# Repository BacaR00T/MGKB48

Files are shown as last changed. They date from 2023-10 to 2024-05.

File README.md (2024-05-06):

# MGKB48
Left and right part connects to the main powerboard with nice!nano (or any another pro micro pinout MCU). 

mgkb48_fin

# MCU file configuration
To be able to use the nice!nano (or any other MCU with nRF52840) and KMK, it's needed to flash the MCU with [CircuitPython](https://learn.adafruit.com/welcome-to-circuitpython/installing-circuitpython) and then compile the [kmk library](https://kmkfw.io/docs/Getting_Started)

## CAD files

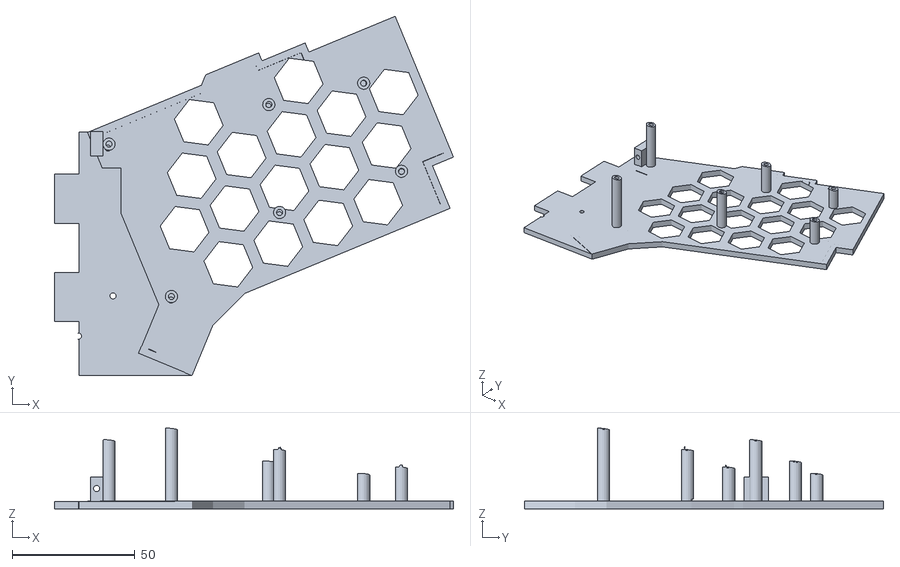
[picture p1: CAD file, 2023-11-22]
STL/MGKB48_RIGHT.stl
162.4 x 146.2 x 32.8

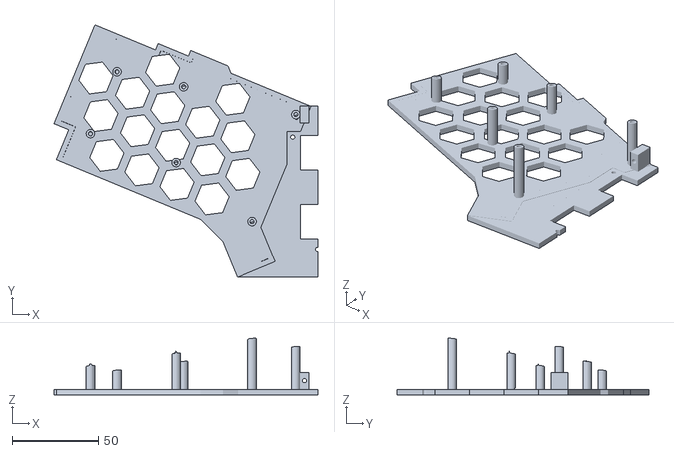
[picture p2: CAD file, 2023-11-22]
STL/MGKB48_LEFT.stl
153.0 x 146.3 x 32.8

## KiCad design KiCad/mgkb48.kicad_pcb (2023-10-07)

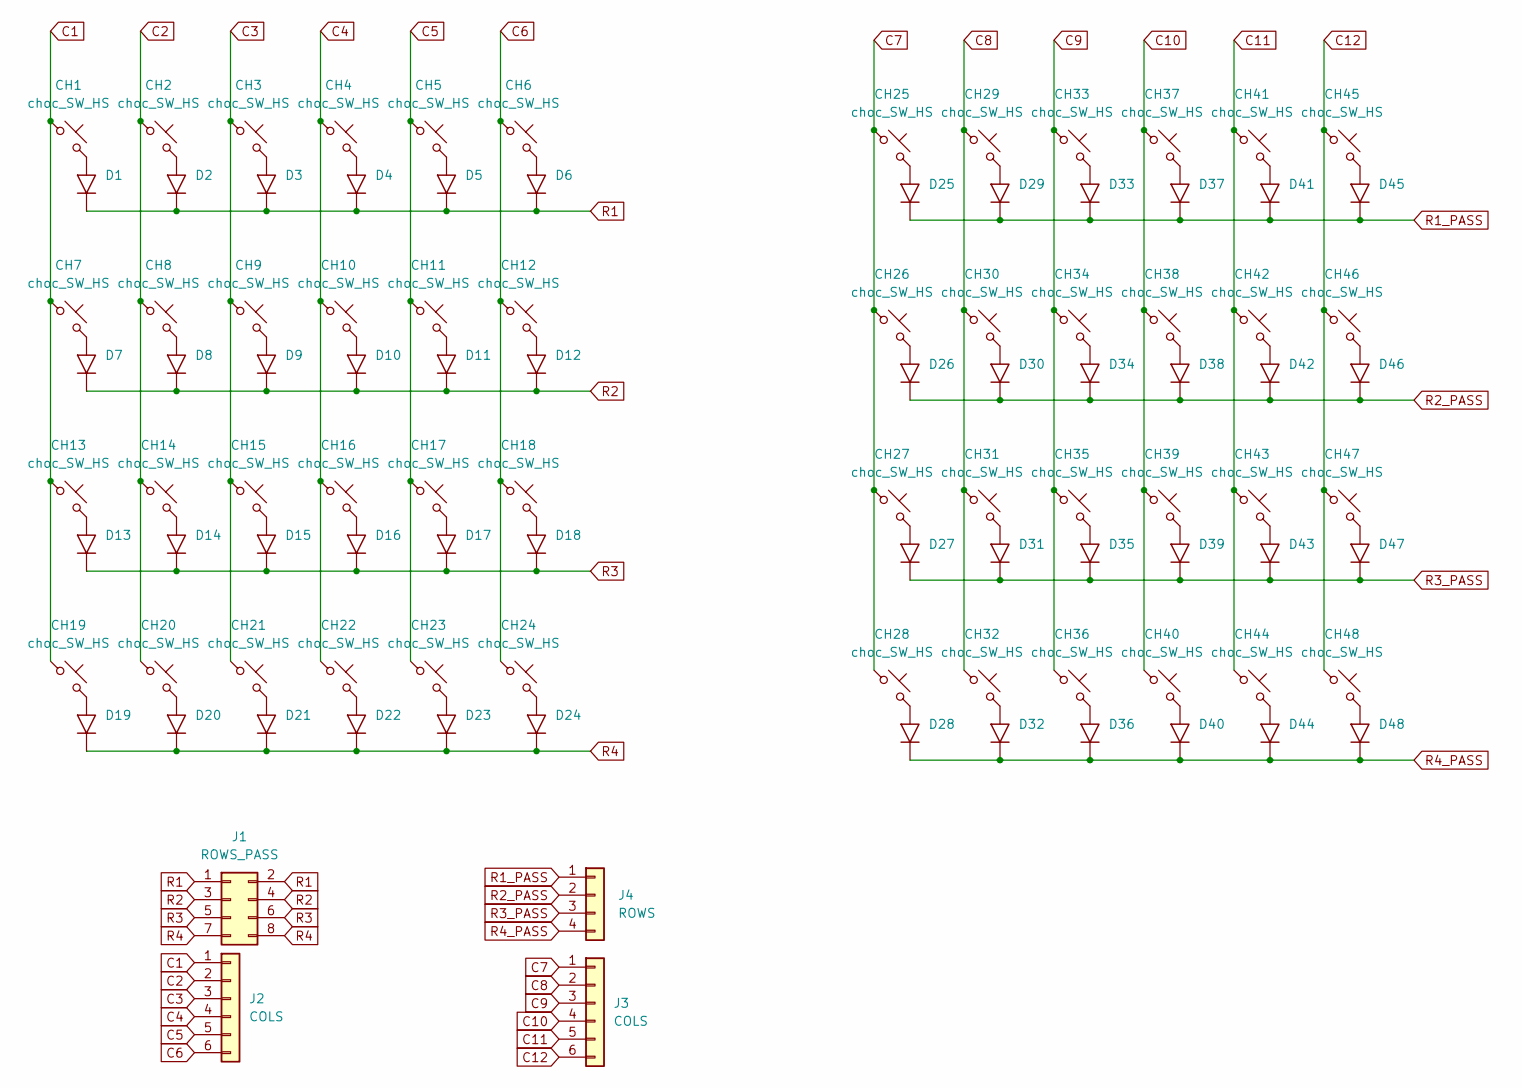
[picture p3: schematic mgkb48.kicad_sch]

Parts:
CH1, CH2, CH3, CH4, CH5, CH6, CH7, CH8, CH9, CH10, CH11, CH12, CH13, CH14, CH15, CH16, CH17, CH18, CH19, CH20, CH21, CH22, CH23, CH24, CH25, CH26, CH27, CH28, CH29, CH30, CH31, CH32, CH33, CH34, CH35, CH36, CH37, CH38, CH39, CH40, CH41, CH42, CH43, CH44, CH45, CH46, CH47, CH48: choc_SW_HS; SW_choc_v1_HS_1u
D1, D2, D3, D4, D5, D6, D7, D8, D9, D10, D11, D12, D13, D14, D15, D16, D17, D18, D19, D20, D21, D22, D23, D24, D25, D26, D27, D28, D29, D30, D31, D32, D33, D34, D35, D36, D37, D38, D39, D40, D41, D42, D43, D44, D45, D46, D47, D48: D_Generic; D_DO-35_P7.62mm_Horizontal
J1: ROWS_PASS; Pins_2x04_2.54mm_TH; Part Number 1-0802FBV0T
J2, J3: COLS; Pins_1x06_2.54mm_TH_SWD; Part Number 1-0601FBV0T
J4: ROWS; Pins_1x04_2.54mm_TH; Part Number 1-0401FBV0T

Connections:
C1: CH1.1, CH7.1, CH13.1, CH19.1, J2.1
C2: CH2.1, CH8.1, CH14.1, CH20.1, J2.2
C3: CH3.1, CH9.1, CH15.1, CH21.1, J2.3
C4: CH4.1, CH10.1, CH16.1, CH22.1, J2.4
C5: CH5.1, CH11.1, CH17.1, CH23.1, J2.5
C6: CH6.1, CH12.1, CH18.1, CH24.1, J2.6
C7: CH25.1, CH26.1, CH27.1, CH28.1, J3.1
C8: CH29.1, CH30.1, CH31.1, CH32.1, J3.2
C9: CH33.1, CH34.1, CH35.1, CH36.1, J3.3
C10: CH37.1, CH38.1, CH39.1, CH40.1, J3.4
C11: CH41.1, CH42.1, CH43.1, CH44.1, J3.5
C12: CH45.1, CH46.1, CH47.1, CH48.1, J3.6
unnamed: CH1.2, D1.2 (A)
unnamed: CH2.2, D2.2 (A)
unnamed: CH3.2, D3.2 (A)
unnamed: CH4.2, D4.2 (A)
unnamed: CH5.2, D5.2 (A)
unnamed: CH6.2, D6.2 (A)
unnamed: CH7.2, D7.2 (A)
unnamed: CH8.2, D8.2 (A)
unnamed: CH9.2, D9.2 (A)
unnamed: CH10.2, D10.2 (A)
unnamed: CH11.2, D11.2 (A)
unnamed: CH12.2, D12.2 (A)
unnamed: CH13.2, D13.2 (A)
unnamed: CH14.2, D14.2 (A)
unnamed: CH15.2, D15.2 (A)
unnamed: CH16.2, D16.2 (A)
unnamed: CH17.2, D17.2 (A)
unnamed: CH18.2, D18.2 (A)
unnamed: CH19.2, D19.2 (A)
unnamed: CH20.2, D20.2 (A)
unnamed: CH21.2, D21.2 (A)
unnamed: CH22.2, D22.2 (A)
unnamed: CH23.2, D23.2 (A)
unnamed: CH24.2, D24.2 (A)
unnamed: CH25.2, D25.2 (A)
unnamed: CH26.2, D26.2 (A)
unnamed: CH27.2, D27.2 (A)
unnamed: CH28.2, D28.2 (A)
unnamed: CH29.2, D29.2 (A)
unnamed: CH30.2, D30.2 (A)
unnamed: CH31.2, D31.2 (A)
unnamed: CH32.2, D32.2 (A)
unnamed: CH33.2, D33.2 (A)
unnamed: CH34.2, D34.2 (A)
unnamed: CH35.2, D35.2 (A)
unnamed: CH36.2, D36.2 (A)
unnamed: CH37.2, D37.2 (A)
unnamed: CH38.2, D38.2 (A)
unnamed: CH39.2, D39.2 (A)
unnamed: CH40.2, D40.2 (A)
unnamed: CH41.2, D41.2 (A)
unnamed: CH42.2, D42.2 (A)
unnamed: CH43.2, D43.2 (A)
unnamed: CH44.2, D44.2 (A)
unnamed: CH45.2, D45.2 (A)
unnamed: CH46.2, D46.2 (A)
unnamed: CH47.2, D47.2 (A)
unnamed: CH48.2, D48.2 (A)
R1: D1.1 (K), D2.1 (K), D3.1 (K), D4.1 (K), D5.1 (K), D6.1 (K), J1.1, J1.2
R1_PASS: D25.1 (K), D29.1 (K), D33.1 (K), D37.1 (K), D41.1 (K), D45.1 (K), J4.1
R2: D7.1 (K), D8.1 (K), D9.1 (K), D10.1 (K), D11.1 (K), D12.1 (K), J1.3, J1.4
R2_PASS: D26.1 (K), D30.1 (K), D34.1 (K), D38.1 (K), D42.1 (K), D46.1 (K), J4.2
R3: D13.1 (K), D14.1 (K), D15.1 (K), D16.1 (K), D17.1 (K), D18.1 (K), J1.5, J1.6
R3_PASS: D27.1 (K), D31.1 (K), D35.1 (K), D39.1 (K), D43.1 (K), D47.1 (K), J4.3
R4: D19.1 (K), D20.1 (K), D21.1 (K), D22.1 (K), D23.1 (K), D24.1 (K), J1.7, J1.8
R4_PASS: D28.1 (K), D32.1 (K), D36.1 (K), D40.1 (K), D44.1 (K), D48.1 (K), J4.4

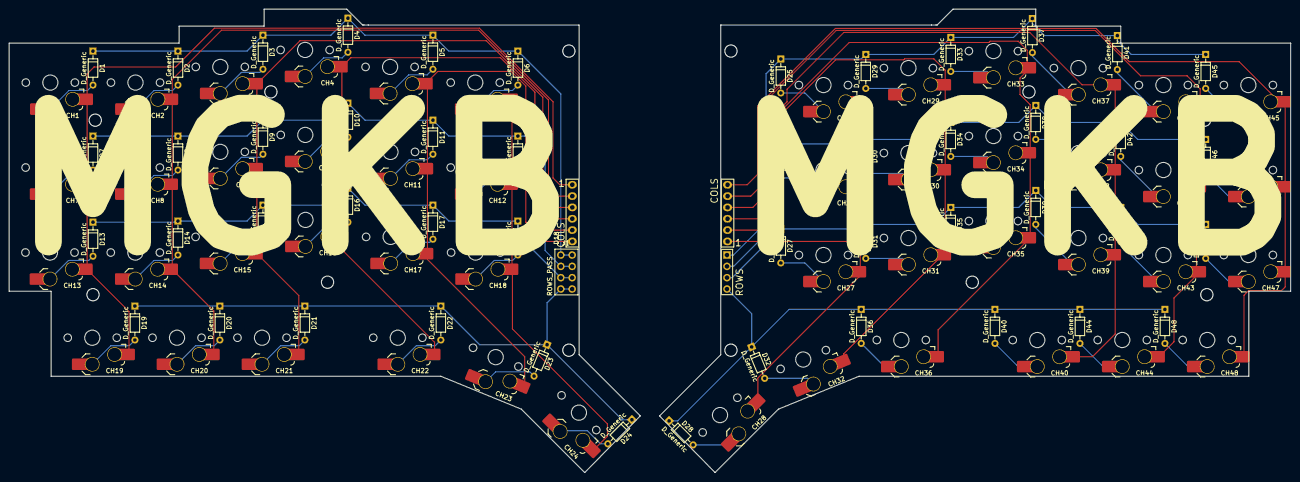
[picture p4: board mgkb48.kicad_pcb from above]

Board: 2 copper layers, 287.3 x 103.9 mm, 100 parts (0 on the bottom side), 68 nets.

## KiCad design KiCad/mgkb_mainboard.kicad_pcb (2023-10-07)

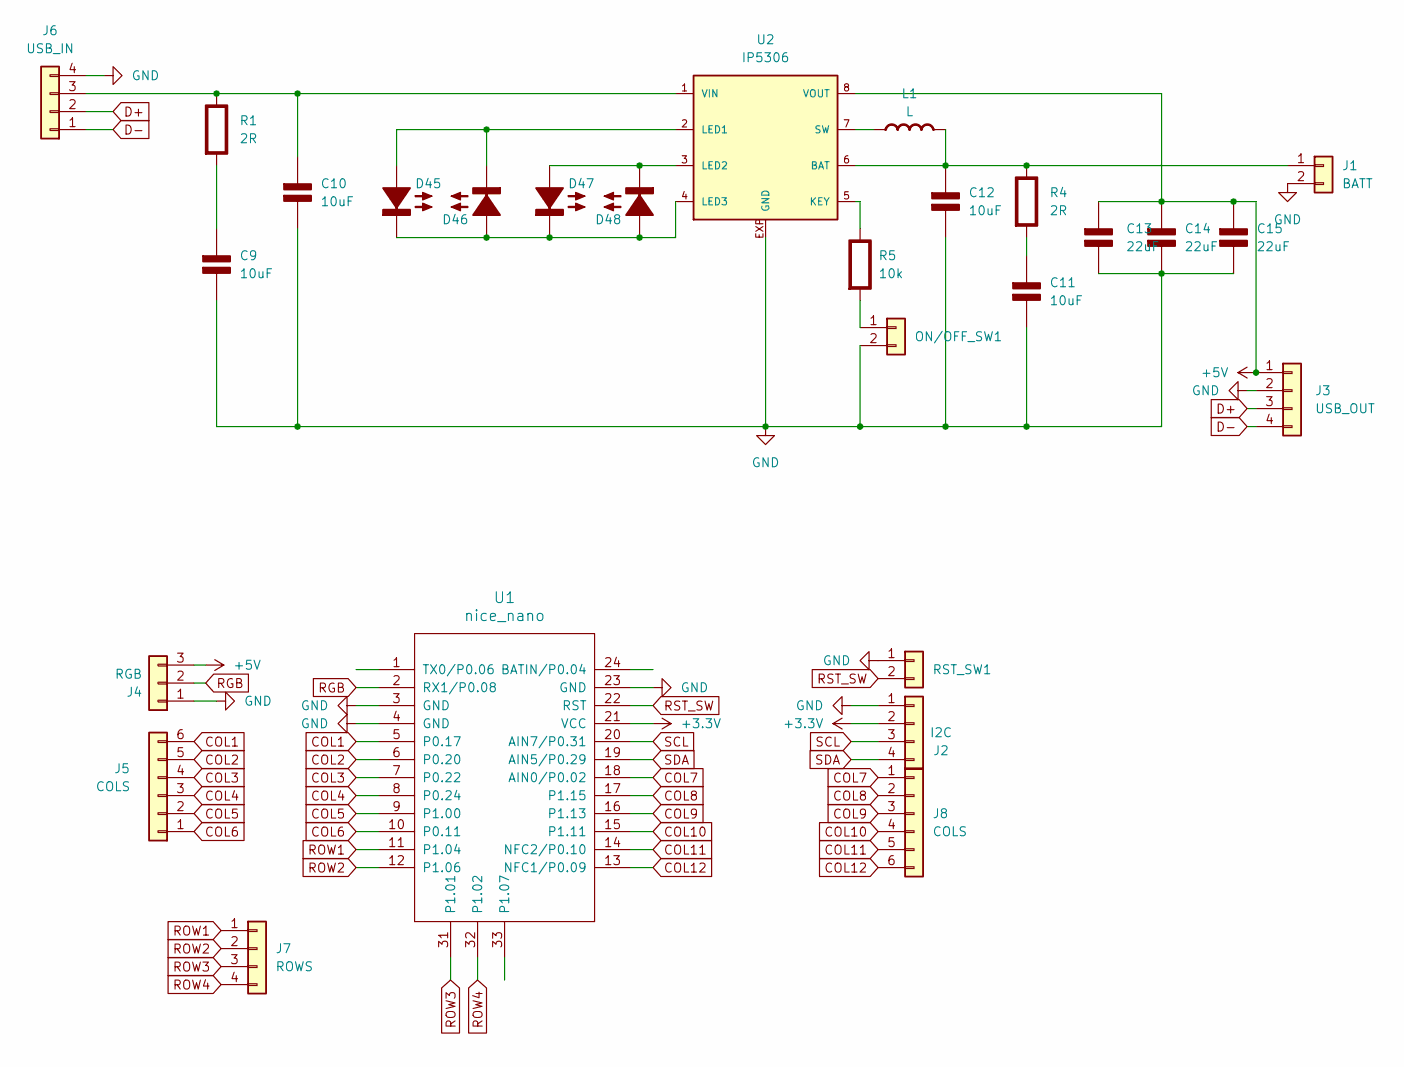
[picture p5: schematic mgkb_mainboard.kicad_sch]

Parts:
C9, C10, C11, C12: 10uF; C_0805; Rating V
C13, C14, C15: 22uF; C_0805; Rating V
D45, D46, D47, D48: type="" model="D-LED" lib="semiconductor.lib"; D_0805_2012Metric; Rating A
J1: BATT; Pins_1x02_2.54mm_TH; Part Number 1-0201FBV0T
J2: I2C; Pins_1x04_2.54mm_TH; Part Number 1-0401FBV0T
J3: USB_OUT; Pins_1x04_2.54mm_TH; Part Number 1-0401FBV0T
J4: RGB; Pins_1x03_2.54mm_TH; Part Number 1-0301FBV0T
J5, J8: COLS; Pins_1x06_2.54mm_TH_SWD; Part Number 1-0601FBV0T
J6: USB_IN; Pins_1x04_2.54mm_TH; Part Number 1-0401FBV0T
J7: ROWS; Pins_1x04_2.54mm_TH_SWD; Part Number 1-0401FBV0T
L1: L; L_Abracon_ASPI-0630LR; Rating A
ON/OFF_SW1: Conn_01x02; Pins_1x02_2.54mm_TH; Part Number 1-0201FBV0T
R1, R4: 2R; R_0805_2012Metric; Rating W
R5: 10k; R_0805_2012Metric; Rating W
RST_SW1: Conn_01x02; Pins_1x02_2.54mm_TH; Part Number 1-0201FBV0T
U1: nice_nano
U2: IP5306; SOP8-P

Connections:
+3V3: J2.2, U1.21 (VCC)
+5V: C13.1 (+), C14.1 (+), C15.1 (+), J3.1, J4.3, U2.8 (VOUT)
COL1: J5.6, U1.5 (P0.17)
COL2: J5.5, U1.6 (P0.20)
COL3: J5.4, U1.7 (P0.22)
COL4: J5.3, U1.8 (P0.24)
COL5: J5.2, U1.9 (P1.00)
COL6: J5.1, U1.10 (P0.11)
COL7: J8.1, U1.18 (AIN0/P0.02)
COL8: J8.2, U1.17 (P1.15)
COL9: J8.3, U1.16 (P1.13)
COL10: J8.4, U1.15 (P1.11)
COL11: J8.5, U1.14 (NFC2/P0.10)
COL12: J8.6, U1.13 (NFC1/P0.09)
D+: J3.3, J6.2
D-: J3.4, J6.1
GND: C9.2 (-), C10.2 (-), C11.2 (-), C12.2 (-), C13.2 (-), C14.2 (-), C15.2 (-), J1.2, J2.1, J3.2, J4.1, J6.4, ON/OFF_SW1.2, RST_SW1.1, U1.3 (GND), U1.4 (GND), U1.23 (GND), U2.EXP (GND)
unnamed: C9.1 (+), R1.2 (-)
unnamed: C10.1 (+), J6.3, R1.1 (+), U2.1 (VIN)
unnamed: C11.1 (+), R4.2 (-)
unnamed: C12.1 (+), J1.1, L1.2 (-), R4.1 (+), U2.6 (BAT)
unnamed: D45.2 (A+), D46.1 (K-), U2.2 (LED1)
unnamed: D45.1 (K-), D46.2 (A+), D47.1 (K-), D48.2 (A+), U2.4 (LED3)
unnamed: D47.2 (A+), D48.1 (K-), U2.3 (LED2)
unnamed: L1.1 (+), U2.7 (SW)
unnamed: ON/OFF_SW1.1, R5.2 (-)
unnamed: R5.1 (+), U2.5 (KEY)
RGB: J4.2, U1.2 (RX1/P0.08)
ROW1: J7.1, U1.11 (P1.04)
ROW2: J7.2, U1.12 (P1.06)
ROW3: J7.3, U1.31 (P1.01)
ROW4: J7.4, U1.32 (P1.02)
RST_SW: RST_SW1.2, U1.22 (RST)
SCL: J2.3, U1.20 (AIN7/P0.31)
SDA: J2.4, U1.19 (AIN5/P0.29)

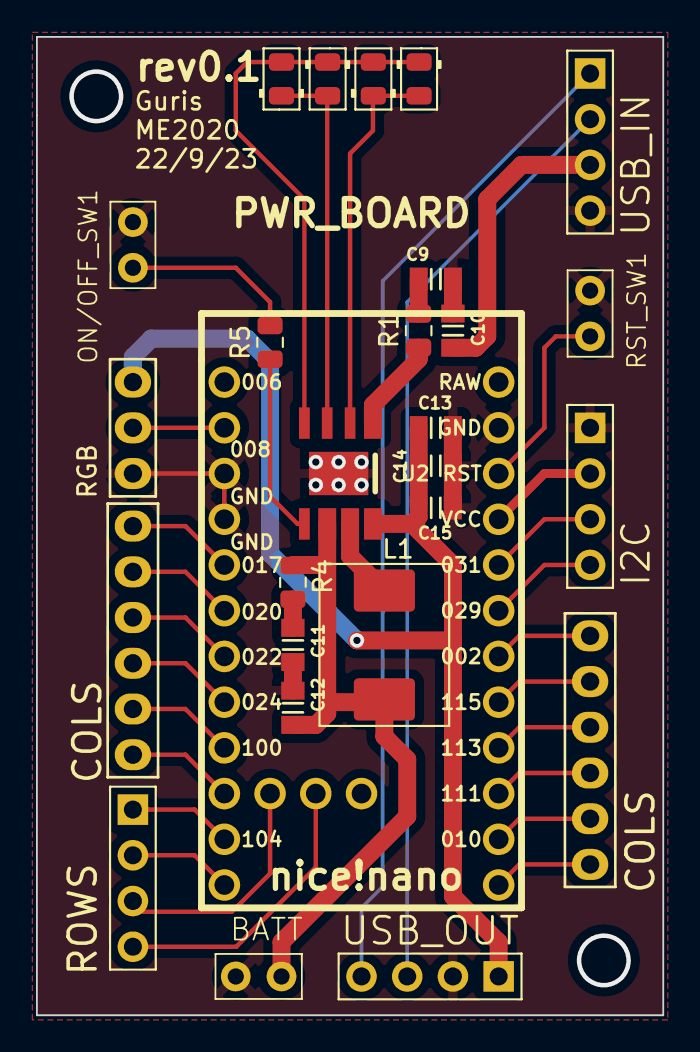
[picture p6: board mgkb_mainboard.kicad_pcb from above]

Board: 2 copper layers, 34.8 x 54.4 mm, 27 parts (0 on the bottom side), 35 nets.

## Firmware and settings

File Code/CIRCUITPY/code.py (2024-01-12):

print("MGKB48")

import board

from kmk.kmk_keyboard import KMKKeyboard
from kmk.keys import KC
from kmk.scanners import DiodeOrientation
from kmk.modules.layers import Layers
from kmk.extensions.media_keys import MediaKeys
from kmk.modules.mouse_keys import MouseKeys

keyboard = KMKKeyboard()
layers_ext = Layers()
keyboard.extensions.append(MediaKeys())
keyboard.modules.append(MouseKeys())

                                                                                                #right
keyboard.col_pins = (board.P0_17, board.P0_20, board.P0_22, board.P0_24, board.P1_00, board.P0_11, board.P0_09, board.P0_10, board.P1_11, board.P1_13, board.P1_15, board.P0_02, )
keyboard.row_pins = (board.P1_04, board.P1_06, board.P1_01, board.P1_02,)                           
keyboard.diode_orientation = DiodeOrientation.COL2ROW

LOWER = KC.MO(1)
RAISE = KC.MO(2)
EXTRA = KC.MO(3)
TRCK_BLL = KC.TRNS

keyboard.keymap = [
    #KEYS
    [
        KC.ESC,     KC.Q,       KC.W,       KC.E,       KC.R,       KC.T,           KC.Y,       KC.U,       KC.I,       KC.O,       KC.P,           KC.BSLS,  
        KC.CAPS,    KC.A,       KC.S,       KC.D,       KC.F,       KC.G,           KC.H,       KC.J,       KC.K,       KC.L,       KC.SCOLON,      KC.QUOT,    
        KC.LSHIFT,  KC.Z,       KC.X,       KC.C,       KC.V,       KC.B,           KC.N,       KC.M,       KC.COMMA,   KC.DOT,     KC.SLASH,       KC.EQL,    
        KC.LCTRL,   KC.LGUI,    KC.LALT,    KC.TAB,     KC.BSPC,    KC.SPC,         TRCK_BLL,    KC.ENT,     KC.MINS,    LOWER,      EXTRA,          RAISE,    
    
    ],
    #LOWER
    [
       KC.TILD,     KC.EXLM,    KC.AT,      KC.HASH,    KC.DLR,     KC.PERC,        KC.CIRC,    KC.AMPR,    KC.ASTR,    KC.LPRN,    KC.RPRN,        KC.UNDS,
       KC.TRNS,     KC.N1,      KC.N2,      KC.N3,      KC.N4,      KC.N5,          KC.N6,      KC.N7,      KC.N8,      KC.N9,      KC.N0,      KC.TRNS,
       KC.TRNS,     KC.TRNS,    KC.TRNS,    KC.TRNS,   KC.LBRC,     KC.RBRC,        KC.MPLY,     KC.MPRV,    KC.MNXT,    KC.VOLD,   KC.VOLU,     KC.MUTE,
       KC.MB_RMB,   KC.MB_MMB,  KC.MB_LMB,  KC.LGUI,   KC.MW_UP,     KC.MW_DN,      KC.TRNS,     KC.BT_CLEAR_BONDS,    KC.TRNS,    KC.TRNS,   KC.TRNS,     KC.TRNS,
    
    ],
    #RAISE  
    [
        KC.F1,       KC.F2,      KC.F3,      KC.F4,     KC.F5,       KC.F6,          KC.F7,       KC.F8,      KC.F9,      KC.F10,    KC.F11,      KC.F12,
        KC.TRNS,     KC.TRNS,    KC.TRNS,    KC.TRNS,   KC.SLCK,     KC.PSCR,        KC.LEFT,     KC.UP,      KC.DOWN,    KC.RIGHT,  KC.TRNS,     KC.TRNS,
        KC.TRNS,     KC.TRNS,    KC.TRNS,    KC.TRNS,   KC.TRNS,     KC.TRNS,        KC.TRNS,     KC.TRNS,    KC.TRNS,    KC.TRNS,   KC.TRNS,     KC.TRNS,
        KC.TRNS,     KC.TRNS,    KC.TRNS,    KC.TRNS,   KC.TRNS,     KC.TRNS,        KC.TRNS,     KC.TRNS,    KC.TRNS,    KC.TRNS,   KC.TRNS,     KC.TRNS,

    ],
    #EXTRA
    [
        KC.RESET,     KC.TRNS,    KC.TRNS,    KC.TRNS,   KC.TRNS,     KC.TRNS,        KC.TRNS,     KC.TRNS,    KC.TRNS,    KC.TRNS,   KC.TRNS,     KC.TRNS,
        KC.TRNS,     KC.TRNS,    KC.TRNS,    KC.TRNS,   KC.TRNS,     KC.TRNS,        KC.TRNS,     KC.TRNS,    KC.TRNS,    KC.TRNS,   KC.TRNS,     KC.TRNS,
        KC.TRNS,     KC.TRNS,    KC.TRNS,    KC.TRNS,   KC.TRNS,     KC.TRNS,        KC.TRNS,     KC.TRNS,    KC.TRNS,    KC.TRNS,   KC.TRNS,     KC.TRNS,
        KC.TRNS,     KC.TRNS,    KC.TRNS,    KC.TRNS,   KC.TRNS,     KC.TRNS,        KC.TRNS,     KC.TRNS,    KC.TRNS,    KC.TRNS,   KC.TRNS,     KC.TRNS,
    ],
]
from kmk.modules.pimoroni_trackball import Trackball, TrackballMode
import busio as io

i2c0 = io.I2C(scl=board.P0_31, sda=board.P0_29)
trackball = Trackball(i2c0, mode=TrackballMode.MOUSE_MODE)
keyboard.modules.append(trackball)
trackball.set_rgbw(255, 255, 255, 255)
trackball.set_red(0)
trackball.set_green(100)
trackball.set_blue(100)
trackball.set_white(0)


keyboard.debug_enabled = True
from kmk.hid import HIDModes

if __name__ == '__main__':
    keyboard.go()
    

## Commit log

2023-10-07 schematics and pcb's 0.1
    [mgkb48.kicad_pcb, mgkb48.kicad_sch, mgkb_mainboard.kicad_pcb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]
2023-11-22 STL's added
    [MGKB48_LEFT.stl, MGKB48_RIGHT.stl]
